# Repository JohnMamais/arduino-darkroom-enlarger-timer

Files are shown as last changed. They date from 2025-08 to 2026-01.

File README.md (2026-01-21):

# Arduino based Darkroom Enlarger Timer _(WIP)_

Here you can find the code, electronics schematics and any 3d printing related to this project. <br/>
An early proof of concept sketch on wokwi is available [here](https://wokwi.com/projects/437627156224860161). <br/>
This is based on a Nano type board but you can adapt it to use anything you have on hand.

## Bill of Materials
- 1 x 3-Pin Male Panel Mount AC Power Supply Socket
- 1 x 2-Contact switch (to turn everything on and off)
- 2 x fuse holder
- 1 x 0.6A fuse (for the arduino)
- 1 x fuse up to specs with your enlarger lamp (usually 1-1.5Amps)
- 1 x 240VAC/24VAC min 0.6A transformer
- 1 x bridge rectifier
- 1 x 2200uF/35V electrolytic capacitor
- 1 x LM7812
- 1 x LM7805
- 1 x 1N4007 diode
- 1 x BC547
- 1 x 10KΩ 1/8Watt resistor
- 1 x 12VDC 2(DC)+3(AC) contact relay (capable of 240 example https://grobotronics.com/12v-dpdt-8a-250v.html)
- 1 x BC547
- 6 x pushbuttons
- 1 x 5 position terminal block (display)
- 1 x 3 position terminal block (AC power)
- 2 x 2 position terminal blocks (enlarger and safelight outlets)
- 1 x Led Display 8-Digit with MAX7219 - **Red** (https://grobotronics.com/led-display-8-digit-with-max7219-red.html)
- 1 x Arduino (I used Nano clone but feel free to modify anything you need to use your prefered board)
- 2 x power outlets (for the enlarger and the safelight)
- 6 x 2 position terminal blocks (optional, for the buttons)
- 1 x Box large enough to hold everything (or the one I have for 3d printing)
- 1 x Breadboard (160mm x 100mm was somewhat comfortable)
- thin wire, multiple colors, 5-12V
- thick wire, multiple colors, 240V
- Solder

### Tools used
- Soldering iron
- Wire cutter
- Lighter to strip the wires
- **Optional** Non-plastic brush to clean mistakes
- **Optional** Wax from a candle to insulate the 240V side of the board for safety. (I used UV resin in my first make of the board and had to clean it out many times to correct mistakes)

## Upcoming updates:
- [X] Bill of materials
- [X] Electronics schematics
- [X] 3d Model to 3D Print a box
- [ ] Assign a button to stop the exposure once the enlarger has started

<br/>
<br/>
<br/>

> [!CAUTION]
> This project involves working with 220V AC and is therefore ~~kind of~~ dangerous. Proceed at your own risk.

Licensed under GPL-V3
Copyright (c) 2025 Ioannis Mamais

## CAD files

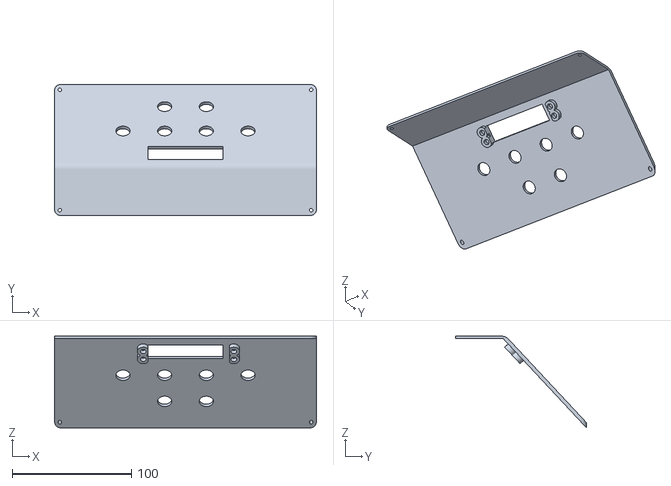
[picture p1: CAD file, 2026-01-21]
3D Printing/lid.stl
220.0 x 110.0 x 77.1

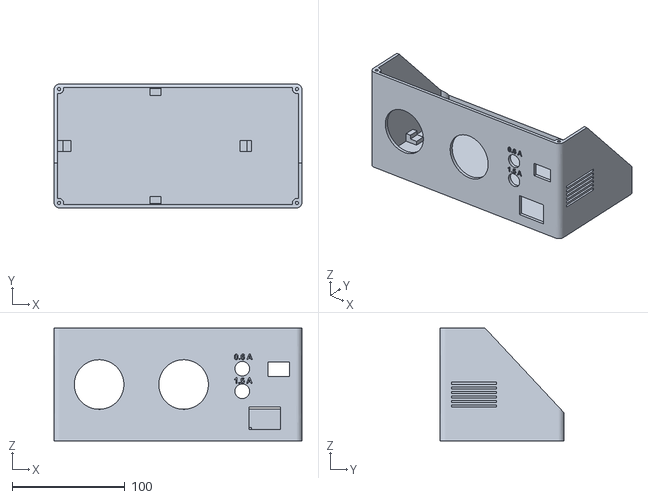
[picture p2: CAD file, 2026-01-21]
3D Printing/box.stl
220.0 x 110.0 x 100.0

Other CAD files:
3D Printing/Darkroom timer box.f3d

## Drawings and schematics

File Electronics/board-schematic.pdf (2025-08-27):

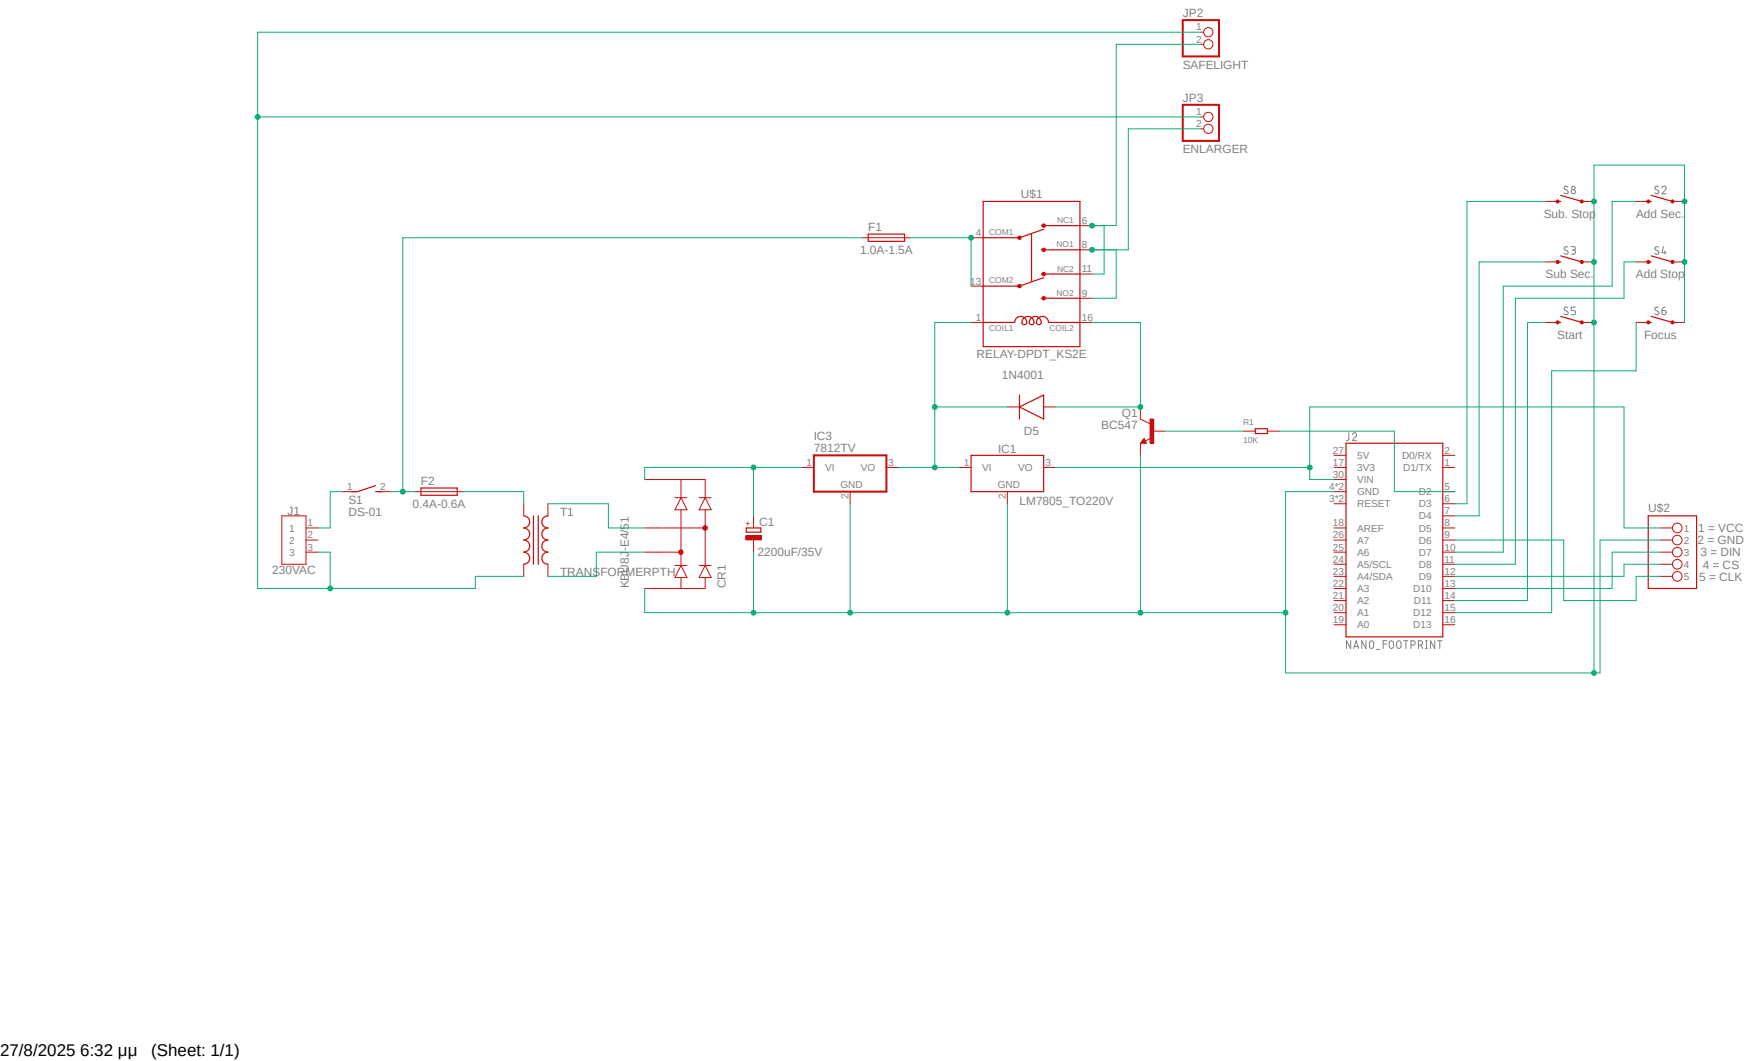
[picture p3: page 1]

2 VO 3 D0/RX 2 D1/TX 1 RESET 3*2 GND 4*2 D2 5 D3 6 D4 7 D5 8 D6 9 D7 10 D8 11 D9 12 D10 13 D11 14 D12 15 VIN 30

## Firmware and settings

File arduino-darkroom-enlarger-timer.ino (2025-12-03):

/*
* This project is part of a DIY darkroom enlarger timer.
* It is licensed under the GNU General Public License V3 License.
*
* Copyright (c) 2025 Ioannis Mamais
*
*/

#include "LedControl.h"
#include <Wire.h>


#define DEBUG 0

#if DEBUG
  #define debug(x) Serial.print(x)
  #define debugln(x) Serial.println(x)
#else
  #define debug(x)
  #define debugln(x)
#endif


const int START_BUTTON = 11;
const int FOCUS_BUTTON = 12;

const int RELAY_PIN = 2;

const int SUB_STOP = 3;
const int SUB_SEC = 4;
const int ADD_SEC = 7;
const int ADD_STOP = 8;

const int LOAD = 10; //CS
const int DATA_IN = 9;
const int CLK = 6;

// init the 8-digit display
// dat, clk, load, num of MAX72xx modules
LedControl lc=LedControl(DATA_IN, CLK, LOAD, 1);

unsigned int time = 10;

// time_c is for the countdown time, keeping the original time intact for reference
unsigned int time_c;

unsigned long buttonDelay = 300; // Minimum delay between button presses (in milliseconds)
unsigned long lastButtonPress = 0; // Store the last time a button was pressed
unsigned long currentMillis = 0; // current time

unsigned long previousMillis = 0; // Will store the last time the countdown updated
bool countdownRunning = false; // Flag to track whether countdown is running

void setup() {

  pinMode(RELAY_PIN, OUTPUT);

  pinMode(START_BUTTON, INPUT_PULLUP);
  pinMode(FOCUS_BUTTON, INPUT_PULLUP);

  pinMode(SUB_STOP, INPUT_PULLUP);
  pinMode(ADD_STOP, INPUT_PULLUP);
  pinMode(SUB_SEC, INPUT_PULLUP);
  pinMode(ADD_SEC, INPUT_PULLUP);

  
  
  // The MAX72XX is in power-saving mode on startup,
  // we have to do a wakeup call
  
  lc.shutdown(0,false);
  // Set the brightness to lowest setting to avoid burning your paper 
  lc.setIntensity(0,0);
  // and clear the display 
  lc.clearDisplay(0);

  displayTime(time);

  Serial.begin(9600);
  debug("Setup complete");
}

void loop() {
  
  currentMillis = millis();

  // Prioritize countdown
  // If countdown is running, update the display every second
  if (countdownRunning) {
    
    // countdown check
    if (time_c < 1 || time_c > time) { // time_c > time is usefull to account for overflow since time variables are unsigned
      countdownRunning = false; // Stop the countdown when it reaches 0
      
      // turn off enlarger head
      stopEnlarger();

      // start debounce timer
      debounceStart();

      // reset the displayed time
      time_c = time;
    }

    // Only update display clock every second
    if (currentMillis - previousMillis >= 1000) {
      previousMillis = currentMillis;
      time_c--;
      displayTime(time_c); // Update the display
    }

  } else {
    
    // Button handling

    // Adding minimum delay to avoid registering the same press multiple times
    if (debounceOk()){

      // Check start button
      if (digitalRead(START_BUTTON) == LOW && time>0) {
        // The countdown is started here and anything that needs to be initialized should be put in here
        debounceStart();
        debugln("timer started");
        
        countdownRunning = true; // start countdown
        time_c = time;
        startEnlarger();
        previousMillis = millis(); 
      }

      // Check focus button
      if (digitalRead(FOCUS_BUTTON) == LOW){
        debounceStart();

        debug("focus button pressed");
        toggleEnlarger();
      }
      
      // Check time buttons
      if (digitalRead(SUB_SEC) == LOW && time>0) {
        debounceStart();
        time--;
        displayTime(time);
      }
      if (digitalRead(ADD_SEC) == LOW && time<9999){
        debounceStart();
        time++;
        displayTime(time);
      }
      if (digitalRead(SUB_STOP) == LOW && time>0){
        debounceStart();
        time/=2;
        displayTime(time);
      }
      if (digitalRead(ADD_STOP) == LOW && time<4999){
        debounceStart();
        time*=2;
        displayTime(time);
      }
    }

  }

}

void displayTime(int x) {

  debug("time remaining: ");
  debugln(x);

  lc.clearDisplay(0);

  int minutes = x / 60;
  int seconds = x % 60;

  int m1 = minutes / 10;
  int m2 = minutes % 10;
  int s1 = seconds / 10;
  int s2 = seconds % 10;

  // Example: 03:45 → m1=0, m2=3, s1=4, s2=5
  // We'll display it on digits 7 to 4 (left side of the display)

  lc.setDigit(0, 7, m1, false);            // Minutes tens
  lc.setDigit(0, 6, m2, true);             // Minutes units + colon (using decimal point)
  lc.setDigit(0, 5, s1, false);            // Seconds tens
  lc.setDigit(0, 4, s2, false);            // Seconds units

  // Optional: Clear remaining digits (3 to 0)
  for (int i = 0; i < 4; i++) {
    lc.setChar(0, i, ' ', false);          // Blank
  }
}

void debounceStart(){
  lastButtonPress = currentMillis;
}

bool debounceOk(){
  return currentMillis - lastButtonPress > buttonDelay;
}

void startEnlarger(){
  digitalWrite(RELAY_PIN, HIGH);
}

void stopEnlarger(){
  digitalWrite(RELAY_PIN, LOW);
}

void toggleEnlarger(){
  // oneliner toggle
  digitalWrite(RELAY_PIN, !digitalRead(RELAY_PIN));
}

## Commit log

2025-08-07 Initial commit
    Initial commit with a general template for the enlarger timer
2025-08-23 Added copyright and corrected typo
    [enlarger.ino]
2025-08-27 Better comments & all buttons are handled with debouncing
2025-08-27 Possibly better oneliner relay toggle
2025-08-27 Added electronics schematic
2025-08-27 Added BOM to README.md
2025-08-27 Updated BOM
2025-10-04 Changed sketch name
    Changed sketch name to allign with what arduino IDE expects.
2025-10-04 Code quality improvements
    Created functions to handle button debouncing functionality
2025-10-04 Debugging is off by default
    Made it so that debug is 0 by default to avoid accidentally leaving it on resulting in larger file size.
    [arduino-darkroom-enlarger-timer.ino]
2026-01-21 add 3d files
    added stl models as well as the Fusion360 files
    [Darkroom timer box.f3d, box.stl, lid.stl]
